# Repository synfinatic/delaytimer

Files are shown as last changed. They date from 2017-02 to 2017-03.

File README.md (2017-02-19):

# 12V/2A Delay Timer

## About

This is a simple adjustable power-off delay timer supporting 5-12V DC and
up to 2A.

When the power is turned on (both 12V and Switch are "on") then
Output is also on.  When Switch is "off", then a timer starts. When 
the timer expires (0-55 seconds) then Output is turned off.

## Specs
 * Voltage: 5-12VDC
 * Max Switched Current: 2A @ 12V
 * Delay: 0-55 seconds 
 * Power requirements when running: 5ma @ 12V
 * Power requrements when turned off: 0ma

## Connections

 * GND - Ground
 * 5-12V - Unswitched 5-12V DC power
 * Switch - Switched 5-12V DC power
 * Output - 2A/5-12V DC delayed power off

## Project Files

 * kicad - [KiCad](http://kicad-pcb.org/) 4.x design files
 * ltspice - [LTSpice](http://www.linear.com/designtools/software/) simulation 

## License and Copyright

Copyright 2017 Aaron Turner

This project is licensed under the [GPLv3](https://www.gnu.org/licenses/gpl-3.0.en.html).

## References

Special thanks to [Rob Paisley](http://home.cogeco.ca/~rpaisley4/LM555.html#30) who helped with the circuit design.

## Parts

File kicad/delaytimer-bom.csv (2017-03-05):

Source | /Users/aturner/GIT/delaytimer/kicad/delaytimer.sch
Kicad Rev | Eeschema 4.0.5
Generated Date | Sunday | March 05 | 2017 'AMt' 10:22:40 AM
Title | Adjustable Delay Timer
Company | Aaron Turner <synfinatic@gmail.com>
Revision | v1.1
Date Issue | 2017-03-05
Comment | https://synfin.net/delaytimer
Comment | Supports 0-55 second delay
Comment | Use to add an adjustible power off delay for 12V applications
Reference | Value | Library | Library Ref
U1 | NE555 | linear | NE555
RV1 | 500k | device | POT_TRIM
Q3 | MMBT3906 | transistors | MMBT3906
Q4 | MMBT3906 | transistors | MMBT3906
Q1 | MMBT3904 | transistors | MMBT3904
Q2 | MMBT3904 | transistors | MMBT3904
C1 | 0.1uf | device | C
R1 | 100k | device | R
C3 | 100uf | device | CP
R2 | 2.2k | device | R
D1 | 1n4148 | device | D
R8 | 2.2k | device | R
R6 | 10k | device | R
R7 | 2.2k | device | R
R4 | 10k | device | R
R5 | 2.2k | device | R
C2 | 0.1uf | device | C
Q5 | IRLML6344 | device | Q_NMOS_GSD
R9 | 1k | device | R
P1 | CONN_01X04 | conn | CONN_01X04
ROpt1 | 100k | device | R

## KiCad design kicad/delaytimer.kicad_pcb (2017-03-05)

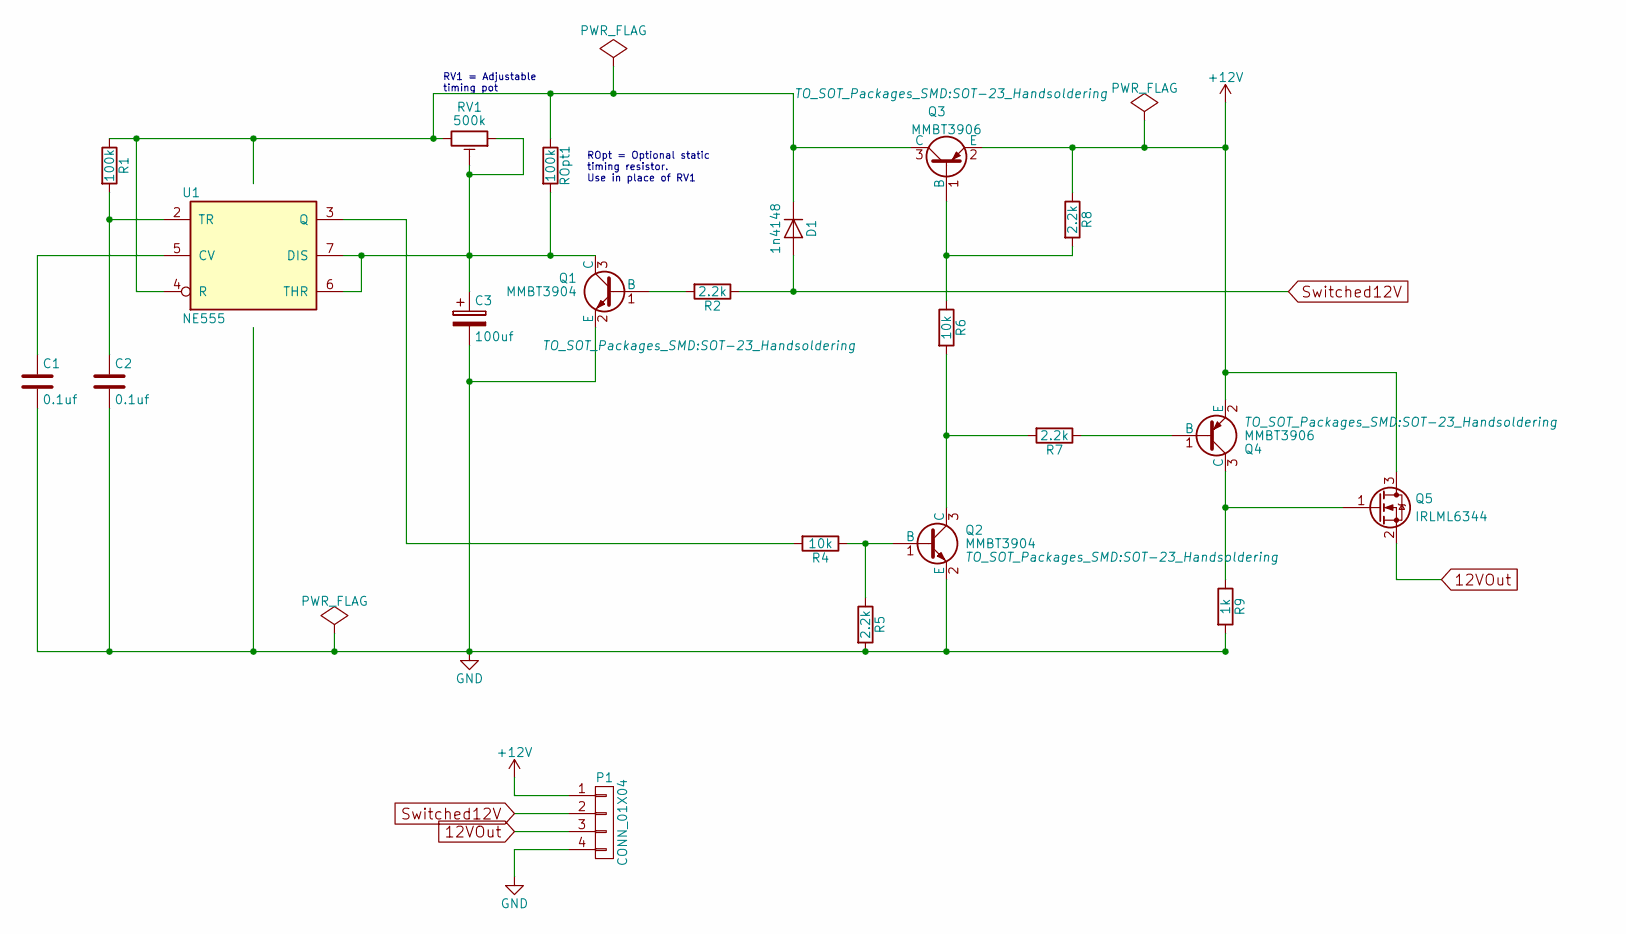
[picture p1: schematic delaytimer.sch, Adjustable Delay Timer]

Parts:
C1, C2: 0.1uf; C_0805_HandSoldering
C3: 100uf; c_elec_6.3x7.7
D1: 1n4148; SOD-123
P1: CONN_01X04; TerminalBlock_Pheonix_PT-3.5mm_4pol
Q1, Q2: MMBT3904; SOT-23_Handsoldering
Q3, Q4: MMBT3906; SOT-23_Handsoldering
Q5: IRLML6344; SOT-23_Handsoldering
R1: 100k; R_0805_HandSoldering
R2, R5, R7, R8: 2.2k; R_0805_HandSoldering
R4, R6: 10k; R_0805_HandSoldering
R9: 1k; R_0805_HandSoldering
ROpt1: 100k; R_0805_HandSoldering
RV1: 500k; Potentiometer_Bourns_3296W_3-8Zoll_Inline_ScrewUp
U1: NE555; SOIC-8_3.9x4.9mm_Pitch1.27mm

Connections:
12VOut: P1.3, Q5.2 (S)
+12V: P1.1, Q3.2 (E), Q4.2 (E), Q5.3 (D), R8.1
GND: C1.2, C2.2, C3.2, P1.4, Q1.2 (E), Q2.2 (E), R5.2, R9.2, U1.1 (GND)
unnamed: C1.1, U1.5 (CV)
unnamed: C2.1, R1.2, U1.2 (TR)
unnamed: C3.1, Q1.3 (C), ROpt1.2, RV1.1, RV1.2, U1.6 (THR), U1.7 (DIS)
unnamed: Q1.1 (B), R2.2
unnamed: Q2.1 (B), R4.1, R5.1
unnamed: Q2.3 (C), R6.2, R7.2
unnamed: Q3.1 (B), R6.1, R8.2
unnamed: Q4.1 (B), R7.1
unnamed: Q4.3 (C), Q5.1 (G), R9.1
unnamed: R4.2, U1.3 (Q)
Switched12V: D1.2 (A), P1.2, R2.1
VCC: D1.1 (K), Q3.3 (C), R1.1, ROpt1.1, RV1.3, U1.4 (R), U1.8 (VCC)

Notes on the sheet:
ROpt = Optional static timing resistor. Use in place of RV1
RV1 = Adjustable timing pot

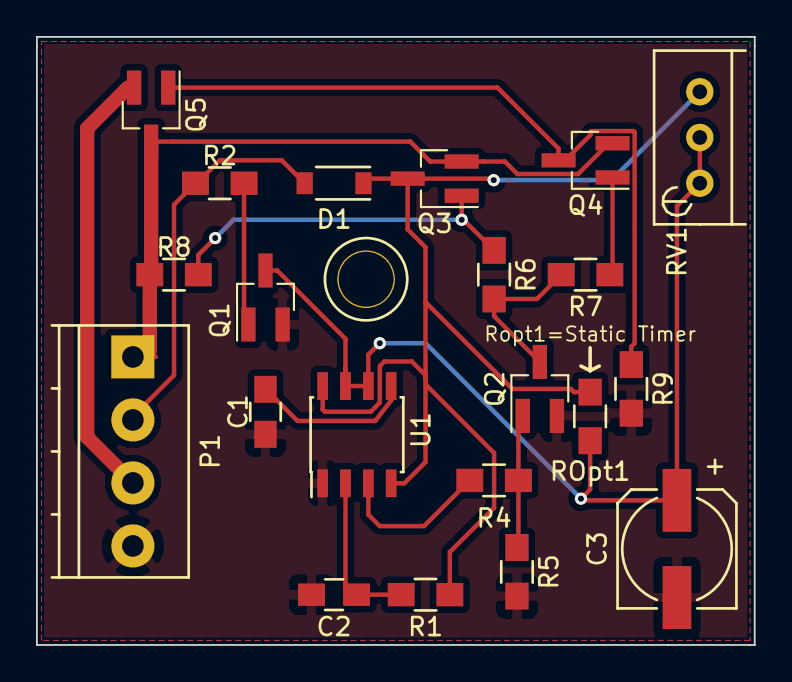
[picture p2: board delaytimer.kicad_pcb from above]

Board: 2 copper layers, 39.9 x 33.8 mm, 21 parts (0 on the bottom side), 15 nets.

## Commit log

2017-02-18 Initial checkin
    Contains:
    - LTSpice design showing the circuit should work
    - First pass at KiCad design for the actual PCB
    [delaytimer.kicad_pcb, delaytimer.sch]
2017-02-19 Update schema / pcb / readme
    - Removed unneeded resistor
    - Reduce vias
    - Fix labels for header
    - Added copper pour on front/back
    - UpdatedBOM
    - Added Makefile for building BOM CSV
    - Update README
    [delaytimer-bom.csv, delaytimer.kicad_pcb, delaytimer.sch]
2017-02-22 Add static resistor option in place of pot
    - Added a static resistor (ROpt) so you can save on the price of a pot
    - Added measurements to the board for making an enclosure
    [delaytimer.kicad_pcb, delaytimer.sch]
2017-02-24 ignore KiCad's autosave created files
2017-03-05 add updated BOM
    [delaytimer-bom.csv]
2017-03-05 Update to v1.1
    - Fix Q1,Q4 which were connected wrong
    - Fix routing of GND to use GND plane
    [delaytimer-bom.csv, delaytimer.kicad_pcb, delaytimer.sch]
